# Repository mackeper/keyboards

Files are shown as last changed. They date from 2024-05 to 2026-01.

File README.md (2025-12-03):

# Keyboards

<div align="center">

Collection of my keyboards and keymaps.

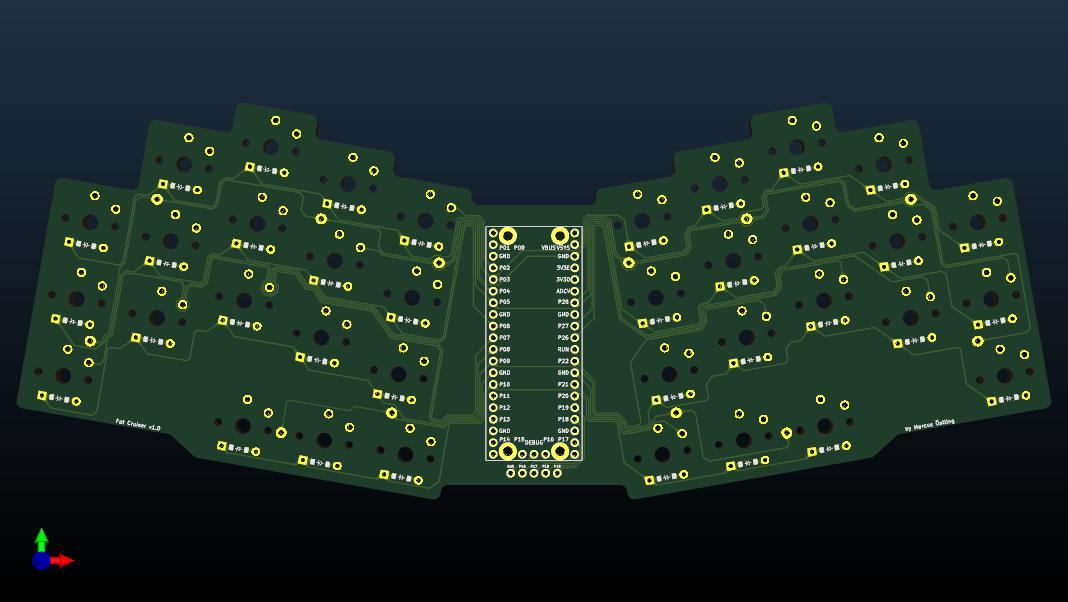
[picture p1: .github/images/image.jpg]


[Keyboards](#keyboards-keyboard) •
[Dependencies](#dependencies-package) •
[Related Projects](#related-projects-link)

</div>

## Keyboards :keyboard:

#### Fat cruiser

* [v1](./fat_cruiser/v1/README.md)
  <details>
  <summary>Preview</summary>

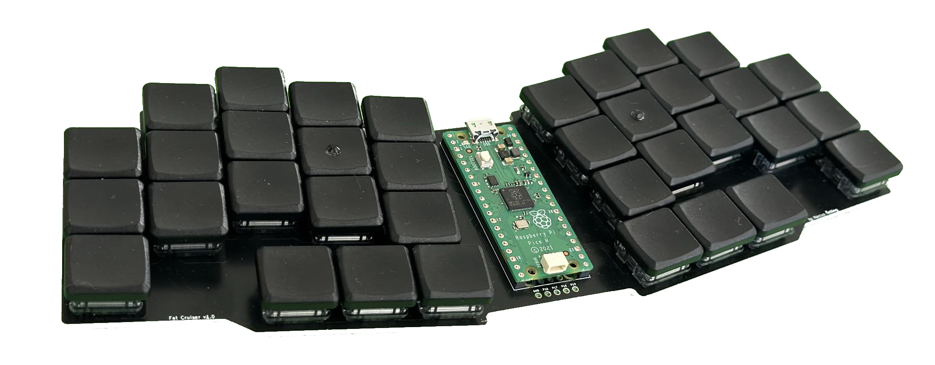
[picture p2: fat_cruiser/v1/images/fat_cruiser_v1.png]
  

  </details>
* [v2](./fat_cruiser/v2/README.md)
  <details>
  <summary>Preview</summary>

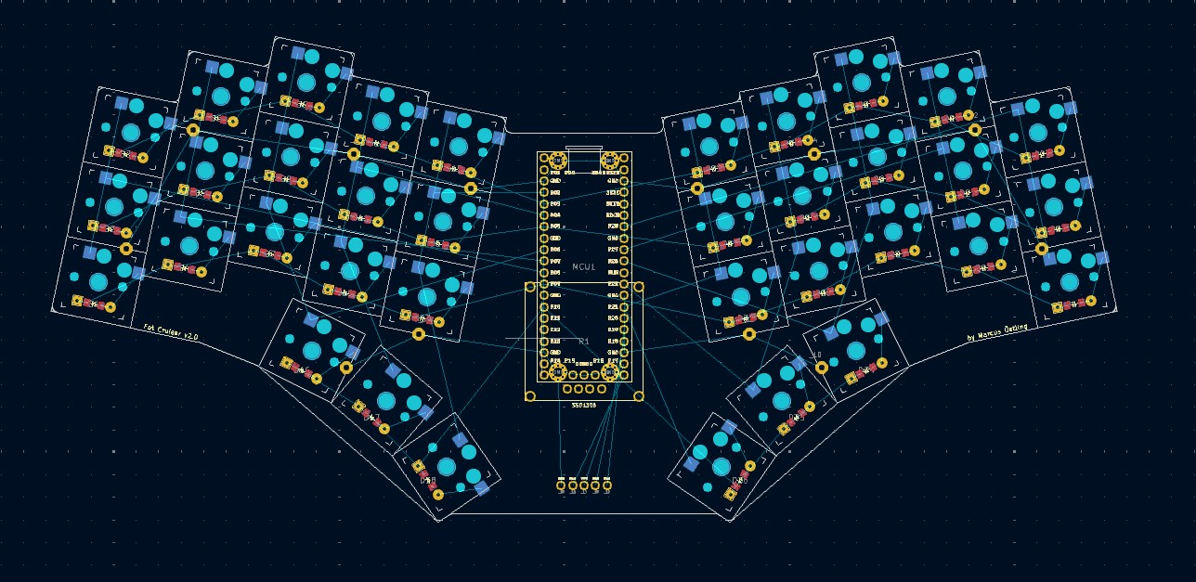
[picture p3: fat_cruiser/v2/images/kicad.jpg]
  

  </details>

## Dependencies :package:

* [KiCad](https://www.kicad.org/)
* [Ergogen](https://github.com/ergogen/ergogen)
  * Install with `npm install -g ergogen`
* [QMK](https://qmk.fm/)
  * Clone or fork the [QMK repository](https://github.com/qmk/qmk.fm)
  * Optional: [Bear](https://github.com/rizsotto/Bear)
    * sudo apt-get install bear
    * bear -- make <keyboard>:<keymap>

## Miscellanceous :sparkles:

### Vim magic

Useful find and replace to add a value to all the coordinates in a KiCad file.

```Vim
:'<,'>s/-*\d\+\.\d\+/\=str2float(submatch(0))+13.97/`
```

### KiCad tips

* Set rotation step to match your keyboard for easier rotation of components
  * See below
* Tools -> Clean up tracks and vias
* Edit -> Edit teardrops
  * Add teardrops to pads for stronger connections to tracks
* Route -> Design Rules Checker
  * Check for errors in your PCB design

#### KiCad Preferences

Set the rotation step to the same value as your keyboard's rotation.

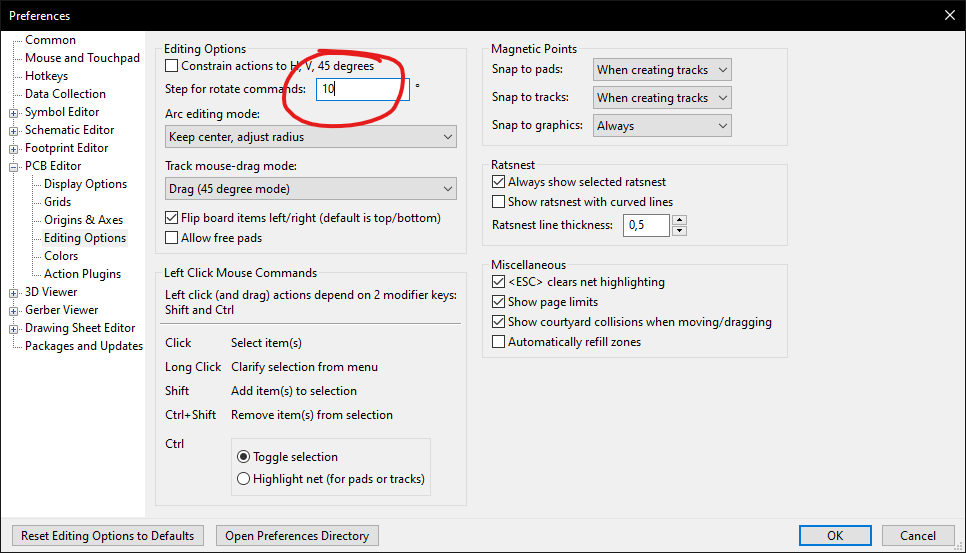
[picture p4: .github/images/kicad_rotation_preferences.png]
KiCad Preferences


## Related Projects :link:

* <https://github.com/benvallack/ergogen>

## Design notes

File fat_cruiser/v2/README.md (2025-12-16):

# Fat Cruiser v2

<div align="center">

<!-- ![Logo](./images/fat_cruiser_v2.png) -->

</div>

See [keymap layout](./qmk/readme.md).

### Images :camera:

<details>
  <summary>Click to expand</summary>
  <div align="center">
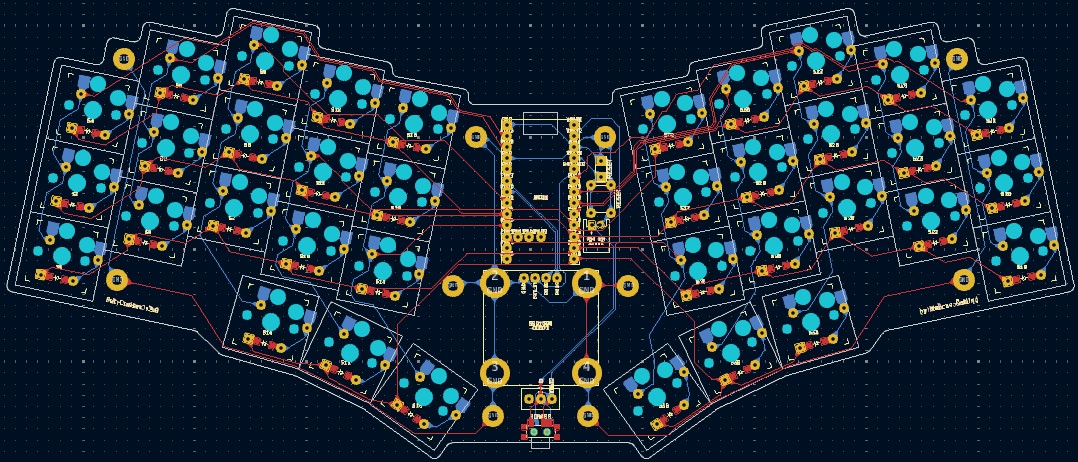
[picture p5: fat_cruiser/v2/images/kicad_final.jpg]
    
  </div>
<div align="center">
</details>

### Changes from v1:
  - Design
    - Increate rotation from 10° to 12°
    - A bit less staggered
      - v1: 0, 16, 7, -5, -5
      - v2: 0, 12, 7, -5, -2
    - Add angle and splay to thumb cluster
      - The thumb should now rest at the center key
  - Hardware
    - Switch to nice!nano v2 (from Raspberry Pi Pico H)
      - Add sockets for MCU
    - Move the diodes to front, inbetween the switches
    - Change switches to Kalih choc redpro (from Kalih choc purple)
      - Hot swappable
    - Change keycaps to MoErgo POM MCC-Profile 1U Keycap (from blank MBK Choc U1)

### Dependencies :gear:

- [KiCad](https://www.kicad.org/)
- [QMK](https://qmk.fm/)
- [Ergogen](https://github.com/berigora/ergogen)
    - `npm install -g ergogen`
- [jscad](https://github.com/jscad/OpenJSCAD.org)
    - `npm install -g @jscad/cli` (this does not work with ergogen generated jscad files yet)
    - `npm install -g @jscad/openjscad` (old version, but works with ergogen generated jscad files)

### Build :hammer:

From within `fat_cruiser/v2/`:

- `ergogen . && for i in output/cases/*.jscad; do npx @jscad/cli@1 "$i" -of stla; done`

### KiCad plot pcb :printer:

- Open pcb in KiCad
- File -> Page Settings
    - Set to A4
- File -> Plot
  - Plot format: PDF
  - Include layers:
    - F.Cu
  - Plot on all layers:
    - F.Cu
    - B.Cu
    - F.Fab
    - B.Fab
    - F.SilkS
    - F.Mask
    - B.Mask
    - Edge.Cuts
    - User.Drawings
    - User.Comments
    - F.Courtyard
    - B.Courtyard
  - Plot drawing sheet
  - Drill marks
    - Actual size
  - Sketch pads on fabrication layers
  - Select output directory

### Parts :nut_and_bolt:

| Part | Price | Url |
| --- | --- | --- |
| PCB | €12.94 (+ €17.39 shipping)  | [jlcpcb](https://jlcpcb.com/) |
| 40 Switches (Kalih choc redpro) | €23.96 | [splitkb](https://splitkb.com/products/kailh-low-profile-choc-switches?variant=33100108234829) |
| 40 Keycaps (MoErgo POM MCC-Profile 1U Keycap) | €19.96 | [splitkb](https://splitkb.com/products/moergo-mcc-profile-1u-keycap?_pos=3&_sid=99ef29720&_ss=r&variant=42898211602691) |
| 100 SMD Diodes | €2.49 | [splitkb](https://splitkb.com/products/kailh-hotswap-sockets?_pos=1&_sid=9303a7619&_ss=r) |
| nice!nano v2 | €25.94 | [splitkb](https://splitkb.com/products/nice-nano?_pos=1&_sid=33e2bd019&_ss=r) |
| SSD1306 OLED Display | €5.89 | [splitkb](https://splitkb.com/products/oled-display?_pos=1&_sid=de7400663&_ss=r&variant=31226608549965) |
| Kailh Hotswap Sockets | €7.95 | [splitkb](https://splitkb.com/products/kailh-hotswap-sockets?_pos=1&_sid=9303a7619&_ss=r) |
| Battery 110 mah | | |
| Connector | | |
| Power switch | | |
| Mill Max Low Profile Sockets | €11.45 | [splitkb](https://splitkb.com/products/mill-max-low-profile-sockets?variant=47060695646555) |
| Total | €55.12 | |

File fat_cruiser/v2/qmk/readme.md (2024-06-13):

# Fat_cruiser

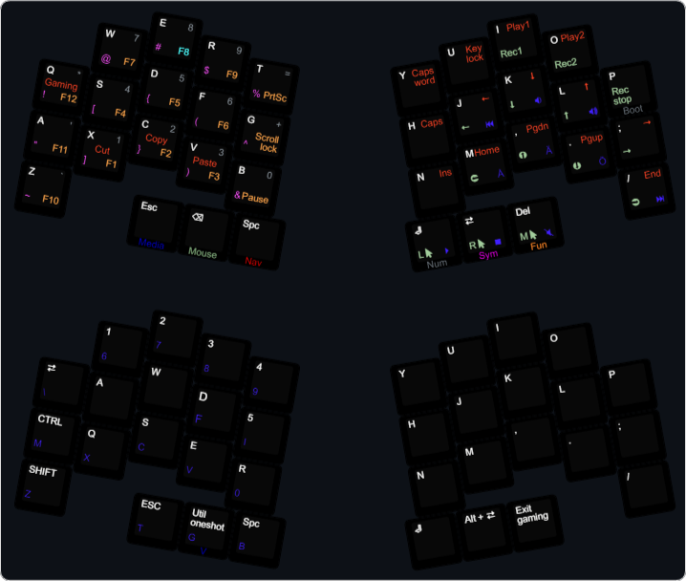
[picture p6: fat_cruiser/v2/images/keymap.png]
fat_cruiser


*A single PCB keyboard that feels like a split one.*
*Small enough to place on top of a laptop keyboard.*

 Keyboard Maintainer: [Marcus Östling](https://github.com/mackeper)  
 Hardware Supported: Raspberry Pi Pico  
 Hardware Availability: *Links to where you can find this hardware*  

## Build

Make example for this keyboard (after setting up your build environment):

    make fat_cruiser:default

Flashing example for this keyboard:

    make fat_cruiser:default:flash

See the [build environment setup](https://docs.qmk.fm/#/getting_started_build_tools) and the [make instructions](https://docs.qmk.fm/#/getting_started_make_guide) for more information. Brand new to QMK? Start with our [Complete Newbs Guide](https://docs.qmk.fm/#/newbs).

## Bootloader

Enter the bootloader in 3 ways:

* **Bootmagic reset**: Hold down the key at (0,0) in the matrix (usually the top left key or Escape) and plug in the keyboard
* **Physical reset button**: Briefly press the button on the back of the PCB - some may have pads you must short instead
* **Keycode in layout**: Press the key mapped to `QK_BOOT` if it is available

## Develop

### Generate compiler_commands.json

`bear -- make fat_cruiser:default`

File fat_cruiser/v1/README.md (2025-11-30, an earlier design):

# Fat Cruiser v1

<div align="center">



</div>

See [keymap layout](./qmk/readme.md).

### Images :camera:

<details>
  <summary>Click to expand</summary>
  <div align="center">
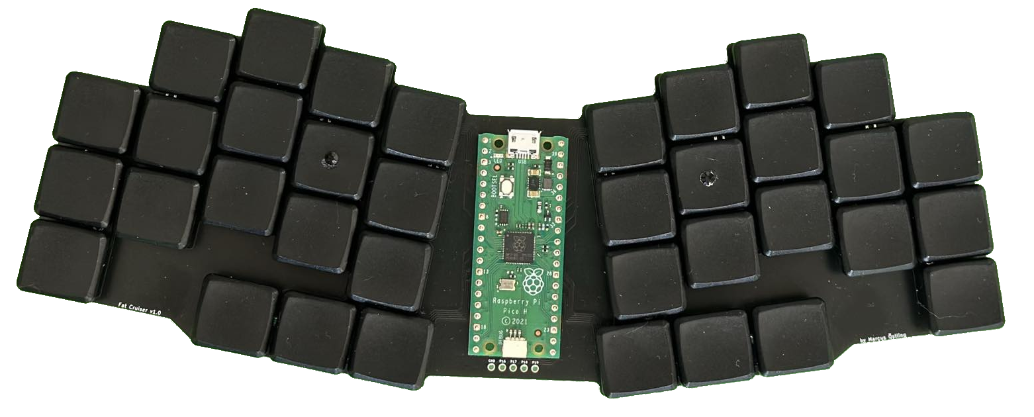
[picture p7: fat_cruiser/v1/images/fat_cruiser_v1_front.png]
    
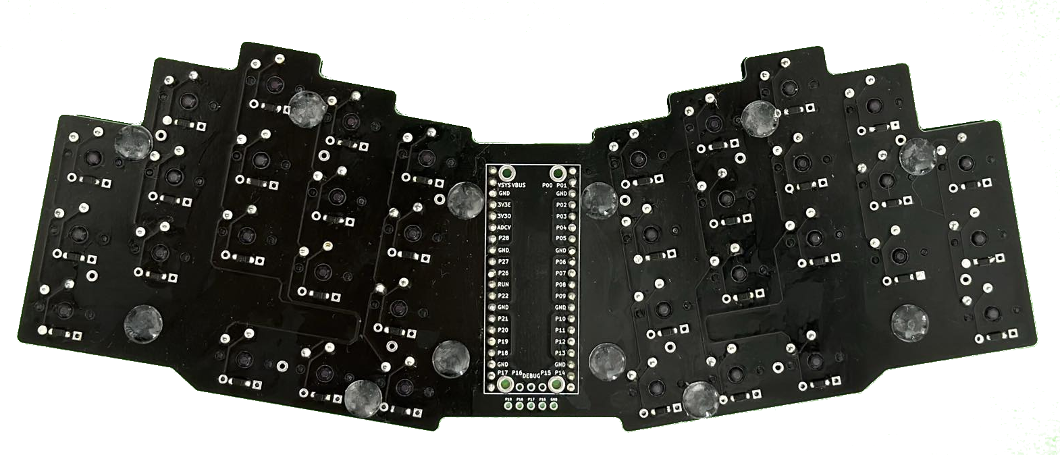
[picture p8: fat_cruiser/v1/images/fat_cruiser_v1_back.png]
    
    
  </div>
<div align="center">
</details>

### Build :hammer:

From within `fat_cruiser/v1/`:

- `ergogen .`

### Parts :nut_and_bolt:

| Part | Price | Url |
|--- | --- | --- |
| PCB | €10.58 ( + €24.76 ) | [jlcpcb](https://jlcpcb.com/) |
| 40 Switches (Kalih choc purple) | €19.80 | [splitkb](https://splitkb.com/products/kailh-low-profile-choc-switches?variant=47265452458331) |
| 40 Keycaps (Blank MBK Choc u1) | €16.36 | [splitkb](https://splitkb.com/products/blank-mbk-choc-low-profile-keycaps?variant=31811491987533) |
| 100 SMD Diodes | €2.49 | [splitkb](https://splitkb.com/products/smd-diodes?variant=42283984027907) |
| Raspberry Pi Pico H | €5.89 | [elektrokit](https://www.electrokit.com/en/raspberry-pi-pico-h) |
| Total | €55.12 | |

## Remarks

- Pinky stagger was too much.
- Thumb cluster should be more centered. And probably angled a bit.
- Could diodes be placed on the front between keys?
- M1 holes seems to be too small. Change to M2?
- Make MCU and switches hot swappable.
- Might want a wider keyboard, increase the space between halfs.
- Add OLED screen or LEDs for layer indication.

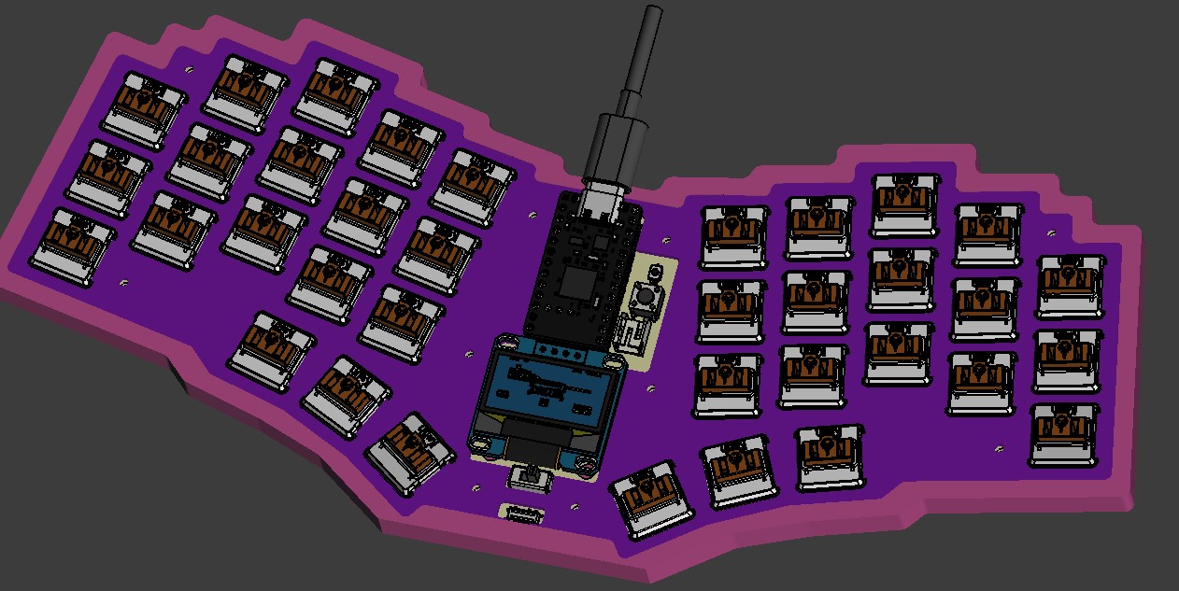
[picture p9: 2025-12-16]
fat_cruiser/v2/images/cad_in_progress.jpg

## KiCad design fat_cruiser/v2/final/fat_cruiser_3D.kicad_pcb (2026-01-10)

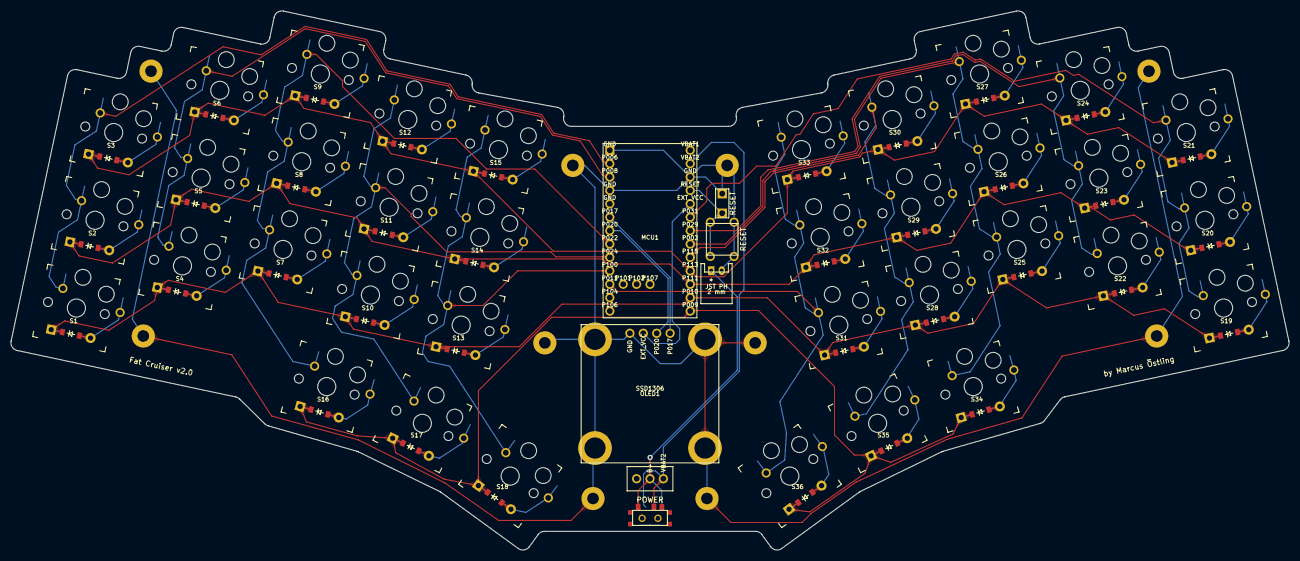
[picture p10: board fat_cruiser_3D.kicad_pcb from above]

Board: 2 copper layers, 242.2 x 102.1 mm, 93 parts (0 on the bottom side), 57 nets.

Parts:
B1: Button2pin
B2: Button4pin
D1, D2, D3, D4, D5, D6, D7, D8, D9, D10, D11, D12, D13, D14, D15, D16, D17, D18, D19, D20, D21, D22, D23, D24, D25, D26, D27, D28, D29, D30, D31, D32, D33, D34, D35, D36: ComboDiode
JST1: JST_PH_S2B-PH-K_02x2.00mm_Angled
MCU1: NiceNano
MH1, MH2, MH3, MH4, MH5, MH6, MH7, MH8, MH9, MH10: MountingHole_Pad_Via
OLED1: OLED_SSD1306
S1, S2, S3, S4, S5, S6, S7, S8, S9, S10, S11, S12, S13, S14, S15, S16, S17, S18, S19, S20, S21, S22, S23, S24, S25, S26, S27, S28, S29, S30, S31, S32, S33, S34, S35, S36: PG1350
T1, T2, T3: text
T4, T5: SPDT_C128955
T6: Slider3Pin

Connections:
B+: JST1.1, T4.1, T5.1, T6.1
EXT_VCC: MCU1.4, OLED1.7
GND: B1.2, B2.3, B2.4, JST1.2, MCU1.0, MCU1.2, MCU1.3, MCU1.4, OLED1.1, OLED1.2, OLED1.3, OLED1.4, OLED1.8
P002: MCU1.7, S25.1, S26.1, S27.1, S34.1
P006: MCU1.1, S1.1, S2.1, S3.1
P008: MCU1.2, S4.1, S5.1, S6.1
P009: D16.1, D17.1, D18.1, D34.1, D35.1, D36.1, MCU1.12
P010: D1.1, D4.1, D7.1, D10.1, D13.1, D19.1, D22.1, D25.1, D28.1, D31.1, MCU1.11
P011: MCU1.10, S31.1, S32.1, S33.1, S36.1
P017: MCU1.5, OLED1.5
P020: MCU1.6, OLED1.6
P022: MCU1.7, S7.1, S8.1, S9.1, S16.1
P024: MCU1.8, S10.1, S11.1, S12.1, S17.1
P029: MCU1.6, S22.1, S23.1, S24.1
P031: MCU1.5, S19.1, S20.1, S21.1
P100: MCU1.9, S13.1, S14.1, S15.1, S18.1
P111: D2.1, D5.1, D8.1, D11.1, D14.1, D20.1, D23.1, D26.1, D29.1, D32.1, MCU1.10
P113: D3.1, D6.1, D9.1, D12.1, D15.1, D21.1, D24.1, D27.1, D30.1, D33.1, MCU1.9
P115: MCU1.8, S28.1, S29.1, S30.1, S35.1
RESET: B1.1, B2.1, B2.2, MCU1.3
VBAT2: MCU1.1, T4.2, T5.2, T6.2
far_bottom: D13.2, S13.2
far_home: D14.2, S14.2
far_thumb: D18.2, S18.2
far_top: D15.2, S15.2
index_bottom: D10.2, S10.2
index_home: D11.2, S11.2
index_thumb: D17.2, S17.2
index_top: D12.2, S12.2
middle_bottom: D7.2, S7.2
middle_home: D8.2, S8.2
middle_thumb: D16.2, S16.2
middle_top: D9.2, S9.2
mirror_far_bottom: D31.2, S31.2
mirror_far_home: D32.2, S32.2
mirror_far_thumb: D36.2, S36.2
mirror_far_top: D33.2, S33.2
mirror_index_bottom: D28.2, S28.2
mirror_index_home: D29.2, S29.2
mirror_index_thumb: D35.2, S35.2
mirror_index_top: D30.2, S30.2
mirror_middle_bottom: D25.2, S25.2
mirror_middle_home: D26.2, S26.2
mirror_middle_thumb: D34.2, S34.2
mirror_middle_top: D27.2, S27.2
mirror_pinky_bottom: D19.2, S19.2
mirror_pinky_home: D20.2, S20.2
mirror_pinky_top: D21.2, S21.2
mirror_ring_bottom: D22.2, S22.2
mirror_ring_home: D23.2, S23.2
mirror_ring_top: D24.2, S24.2
pinky_bottom: D1.2, S1.2
pinky_home: D2.2, S2.2
pinky_top: D3.2, S3.2
ring_bottom: D4.2, S4.2
ring_home: D5.2, S5.2
ring_top: D6.2, S6.2

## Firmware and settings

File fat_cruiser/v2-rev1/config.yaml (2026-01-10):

meta:
  version: v2.0.0
  author: Marcus Östling

units:
  rotation: -12
  pcx: cx + 8
  pcy: cy + 8
  padding: 4
  margin: 0.4

  plate_thickness: 1.5

  screwSize: 1 # M2 screws
  insetSize: 2.5 # M2 screws
  mountSize: 4 # M2 screws

  lever_width: 18
  lever_height: 8
  lever_notch: 4

points:
  rotate: rotation
  key:
    spread: cx
    padding: cy
  zones:
    board:
      anchor:
        shift: [64, -100]
      rows:
        bottom:
          row_net: P010 # D16
        home:
          row_net: P111 # D14
        top:
          row_net: P113 # D15
      columns:
        pinky:
          rows.thumb.skip: true
          key:
            col_net: P006 # D1
            mirror.col_net: P031 # D21
        ring:
          key:
            stagger: 12
            col_net: P008 # D0
            mirror.col_net: P029 # D20
          rows.thumb.skip: true
        middle.key:
          stagger: 7
          col_net: P022 # D4
          mirror.col_net: P002 # D19
        index.key:
          stagger: -5
          col_net: P024 # D5
          mirror.col_net: P115 # D18
        far.key:
          stagger: -2
          col_net: P100 # D6
          mirror.col_net: P011 # D7
    thumbrow:
      anchor:
        ref: board_middle_bottom
        shift: [0.75cx, -2cy + 10.3]
        rotate: -4
      rows:
        thumb:
          row_net: P009 # D10
      columns:
        middle.key:
          col_net: P022
          mirror.col_net: P002
        index.key:
          col_net: P024
          mirror.col_net: P115
          splay: -10
          origin: [-0.5cx, -0.5cy]
        far.key:
          col_net: P100
          mirror.col_net: P011
          splay: -10
          origin: [-0.5cx, -0.5cy]
  mirror:
    ref: board_index_top
    distance: 5.1*cx

outlines:
  board:
    - what: polygon
      operation: stack
      points:
        - ref: board_pinky_top
          shift: [-0.6cx, 0.6cy]
        - ref: board_pinky_top
          shift: [0cx, 0.6cy]
        - ref: board_pinky_top
          shift: [0cx, 1cy]
        - ref: board_pinky_top
          shift: [0.4cx, 1cy]
        - ref: board_ring_top
          shift: [-0.6cx, 0.6cy]
        - ref: board_ring_top
          shift: [0.4cx, 0.6cy]
        - ref: board_middle_top
          shift: [-0.6cx, 0.6cy]
        - ref: board_middle_top
          shift: [0.6cx, 0.6cy]
        - ref: board_index_top
          shift: [-0.4cx, 0.62cy]
        - ref: board_index_top
          shift: [0.57cx, 0.62cy]
        - ref: board_far_top
          shift: [-0.4cx, 0.57cy]
        - ref: board_far_top
          shift: [0.6cx, 0.6cy]
        - ref: board_far_top
          shift: [0.6cx, 0.4cy]

        - ref: mirror_board_far_top
          shift: [0.6cx, 0.4cy]
        - ref: mirror_board_far_top
          shift: [0.6cx, 0.6cy]
        - ref: mirror_board_far_top
          shift: [-0.4cx, 0.57cy]
        - ref: mirror_board_index_top
          shift: [0.57cx, 0.62cy]
        - ref: mirror_board_index_top
          shift: [-0.4cx, 0.62cy]
        - ref: mirror_board_middle_top
          shift: [0.6cx, 0.6cy]
        - ref: mirror_board_middle_top
          shift: [-0.6cx, 0.6cy]
        - ref: mirror_board_ring_top
          shift: [0.4cx, 0.6cy]
        - ref: mirror_board_ring_top
          shift: [-0.6cx, 0.6cy]
        - ref: mirror_board_pinky_top
          shift: [0.4cx, 1cy]
        - ref: mirror_board_pinky_top
          shift: [0cx, 1cy]
        - ref: mirror_board_pinky_top
          shift: [0cx, 0.6cy]
        - ref: mirror_board_pinky_top
          shift: [-0.6cx, 0.6cy]
        - ref: mirror_board_pinky_bottom
          shift: [-0.6cx, -0.6cy]
        - ref: mirror_board_pinky_bottom
          shift: [1.86cx, -0.6cy]
        - ref: mirror_thumbrow_middle_thumb
          shift: [-0.6cx, -0.6cy]
        - ref: mirror_thumbrow_middle_thumb
          shift: [0.5cx, -0.6cy]
        - ref: mirror_thumbrow_far_thumb
          shift: [-0.5cx, -0.6cy]
        - ref: mirror_thumbrow_far_thumb
          shift: [0.5cx, -0.6cy]
        - ref: mirror_thumbrow_far_thumb
          shift: [0.6cx, -0.6cy]
        - ref: mirror_thumbrow_far_thumb
          shift: [0.6cx, -0.3cy]

        - ref: thumbrow_far_thumb
          shift: [0.6cx, -0.3cy]
        - ref: thumbrow_far_thumb
          shift: [0.6cx, -0.6cy]
        - ref: thumbrow_far_thumb
          shift: [0.5cx, -0.6cy]
        - ref: thumbrow_far_thumb
          shift: [-0.5cx, -0.6cy]
        - ref: thumbrow_middle_thumb
          shift: [0.5cx, -0.6cy]
        - ref: thumbrow_middle_thumb
          shift: [-0.5cx, -0.6cy]
        - ref: board_pinky_bottom
          shift: [1.86cx, -0.6cy]
        - ref: board_pinky_bottom
          shift: [-0.6cx, -0.6cy]

  cutout_board:
    - what: outline
      name: board
      fillet: 1.5
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

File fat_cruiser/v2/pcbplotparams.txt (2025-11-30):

		(pcbplotparams
			(layerselection 0x0000000_7fffffff)
			(plot_on_all_layers_selection 0x000d330_80000001)
			(disableapertmacros no)
			(usegerberextensions no)
			(usegerberattributes yes)
			(usegerberadvancedattributes yes)
			(creategerberjobfile yes)
			(dashed_line_dash_ratio 12.000000)
			(dashed_line_gap_ratio 3.000000)
			(svgprecision 4)
			(plotframeref yes)
			(viasonmask no)
			(mode 1)
			(useauxorigin no)
			(hpglpennumber 1)
			(hpglpenspeed 20)
			(hpglpendiameter 15.000000)
			(pdf_front_fp_property_popups yes)
			(pdf_back_fp_property_popups yes)
			(dxfpolygonmode yes)
			(dxfimperialunits yes)
			(dxfusepcbnewfont yes)
			(psnegative no)
			(psa4output no)
			(plotreference yes)
			(plotvalue yes)
			(plotfptext yes)
			(plotinvisibletext no)
			(sketchpadsonfab yes)
			(subtractmaskfromsilk no)
			(outputformat 4)
			(mirror no)
			(drillshape 2)
			(scaleselection 1)
			(outputdirectory "../")
		)

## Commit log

2024-05-09 add mounting holes to rp2040
2024-05-09 add pcb file
    [main.kicad_pcb]
2024-05-10 Work on pcb
    [main.kicad_pcb]
2024-05-10 Add gerber files
    [main-B_Cu.gbr, main-B_Mask.gbr, main-B_Paste.gbr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]
2024-06-19 Add some remarks
    [main.kicad_pcb]
2024-06-19 Start working on 3d printable cases
2024-08-18 Fix oled and some cutout points
    [config.yaml]
2024-08-29 Work on v2
    [main.kicad_pcb]
2025-10-14 Fix enter and start with auto click feature
    [led.c]
2025-11-30 Working on fat_cruiser v2
    [main.kicad_pcb, pcbplotparams.txt]
2025-11-30 Create case base
2025-11-30 Add plate case
2025-12-01 Replace nvim with platform-specific sed/PowerShell
2025-12-13 ordered final
    [fat_cruiser-B_Cu.gbr, fat_cruiser-B_Mask.gbr, fat_cruiser-B_Paste.gbr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]
2025-12-16 Added 3D models to the kicad footprints
    [fat_cruiser_3D.kicad_pcb]
2025-12-21 Update the case
2026-01-10 Added v2-rev1, same features just a few updates to footprints and config
    [fat_cruiser_3D.kicad_pcb]
